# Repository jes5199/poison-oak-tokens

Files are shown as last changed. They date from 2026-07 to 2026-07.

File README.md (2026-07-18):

# Poison-Oak Tokens

Physical tokens to help Scouts learn to recognize poison oak by its
leaves-of-three shape — a safe, touchable way to study the plant, given as a
reward for learning to spot it in the field.

Each token is a printable coin/bead bearing a trifoliate poison-oak leaf,
traced from a real leaf illustration.

<p align="center">
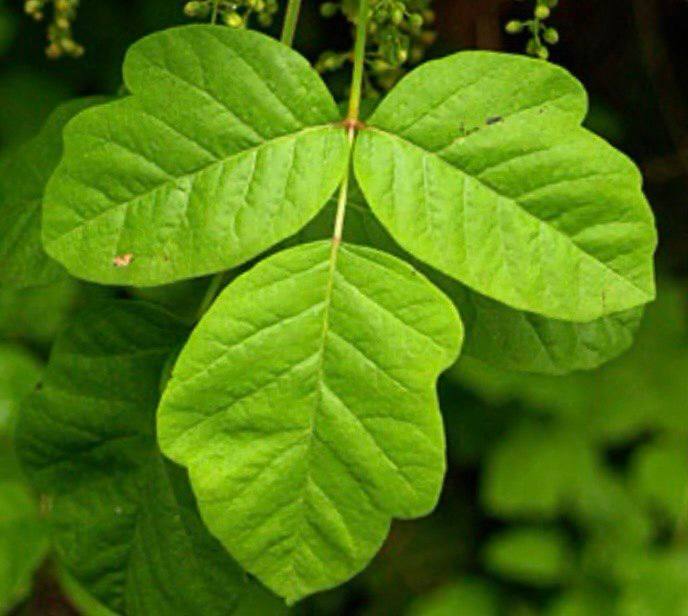
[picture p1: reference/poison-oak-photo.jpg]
Poison oak — real leaf photograph

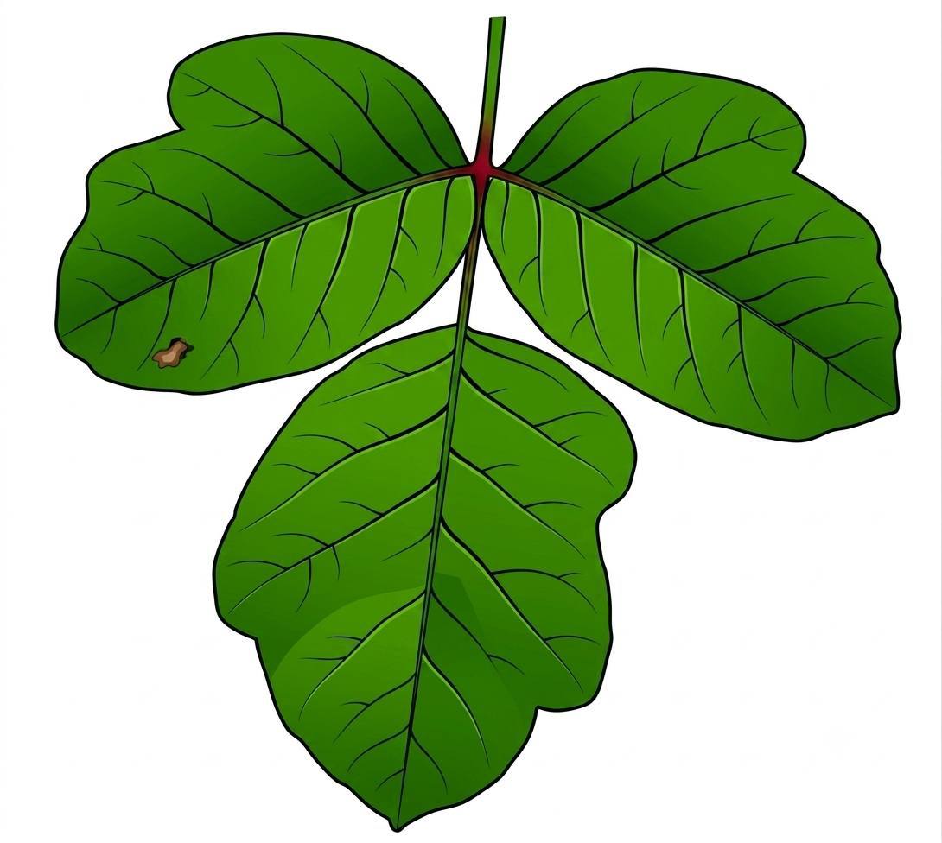
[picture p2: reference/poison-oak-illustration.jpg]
Poison oak illustration — the origin art for the relief

</p>

*Left: the real plant. Right: the illustration the tokens' relief was traced
from (line art extracted by black-hat morphology, baked to grayscale
heightmaps, embossed via OpenSCAD `surface()`).* Three final designs, each
a self-contained OpenSCAD model: the `.scad` plus the two grayscale heightmaps
in its folder reproduce the STL exactly.

| Token | Design | Hole | Thickness |
|---|---|---|---|
| **20 mm** (`20mm/`) | Single-vein: one midrib stroke per leaflet | Ø3.0 mm | 3.20 mm |
| **25 mm** (`25mm/`) | The same single-vein design at 1.25× | Ø3.0 mm | 3.20 mm |
| **40 mm** (`40mm/`) | Full veins, bold strokes, on a chunky 5.70 mm deep-relief body | Ø3.0 mm | 5.70 mm |

Every token is a **bead**: a vertical through-hole sits on the stem's own
implied axis (the leaf leans ~5.8° — the hole follows the stem line, not the
coin's centerline), sized for twine and placed tangent to the raised border so
it never cuts the edge ring. The **front** face is an embossed leaf medallion
(raised silhouette, debossed veins, raised border ring running to the rim).
The **back** face is the same leaf engraved as line art, mirrored *and rotated*
so the hole lands on the stem line on both faces, with a thin flat land at the
rim for a clean first layer.

## The tokens

### 20 mm — single vein per leaflet

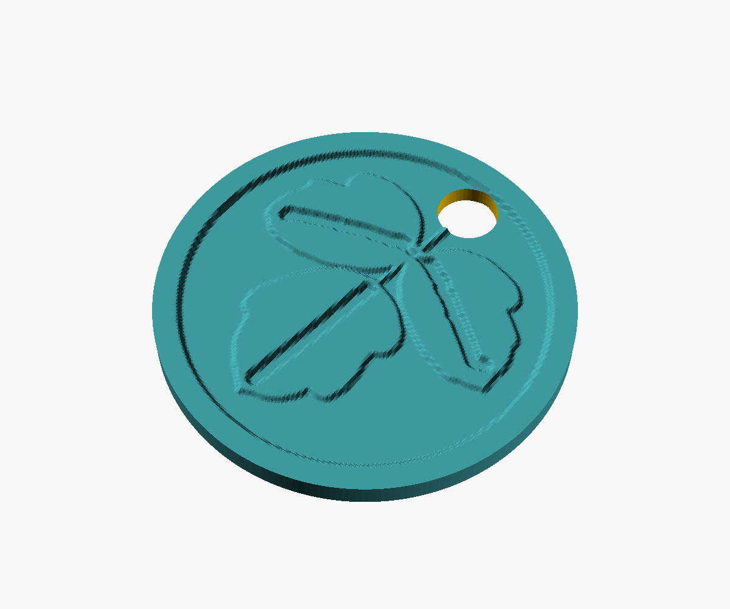
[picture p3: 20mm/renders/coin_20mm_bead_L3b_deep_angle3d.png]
20mm token, angled 3D


| Front (what prints) | Back (what prints) | Top-down 3D | Back face 3D |
|---|---|---|---|
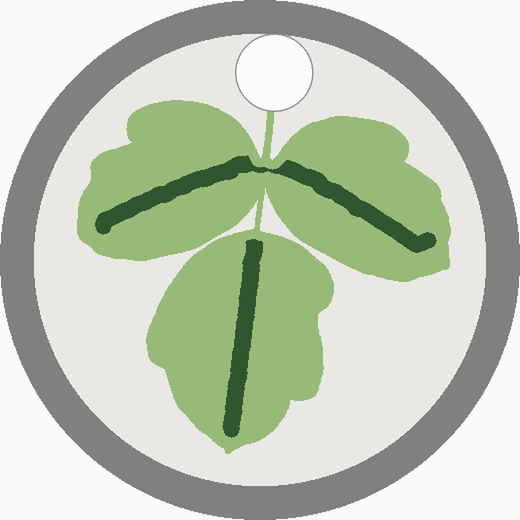
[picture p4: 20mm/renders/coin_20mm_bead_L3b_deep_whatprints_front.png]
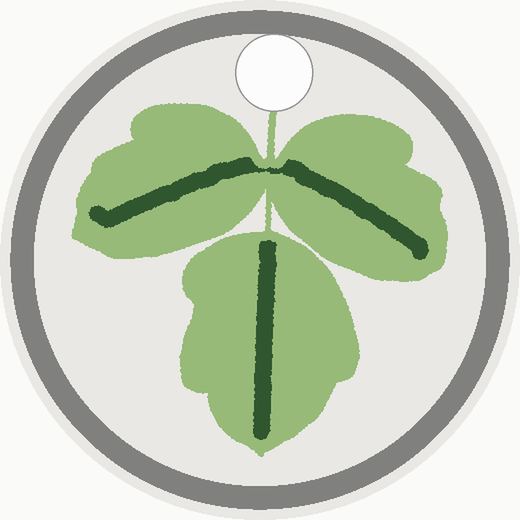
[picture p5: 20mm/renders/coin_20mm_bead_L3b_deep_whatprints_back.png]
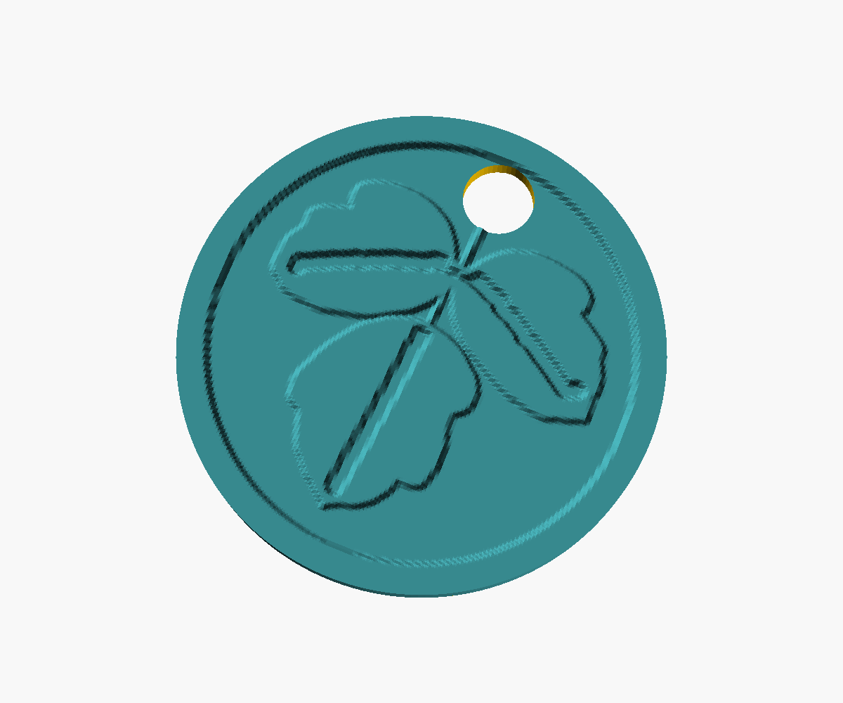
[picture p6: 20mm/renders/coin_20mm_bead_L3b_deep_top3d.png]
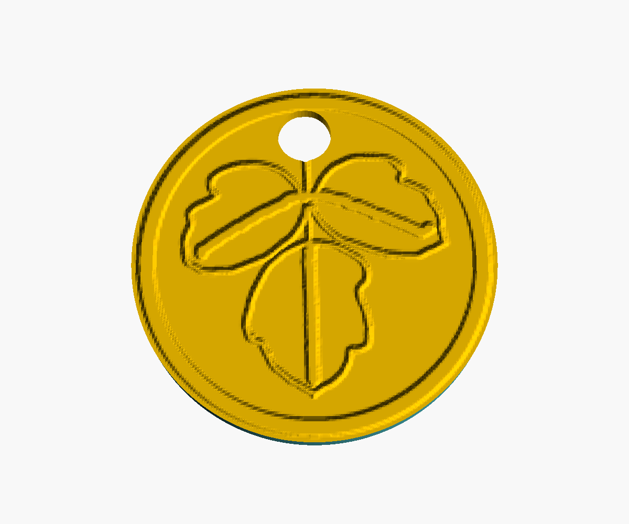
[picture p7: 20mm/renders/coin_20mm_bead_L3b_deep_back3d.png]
|  |  |  |  |

### 25 mm — single vein per leaflet

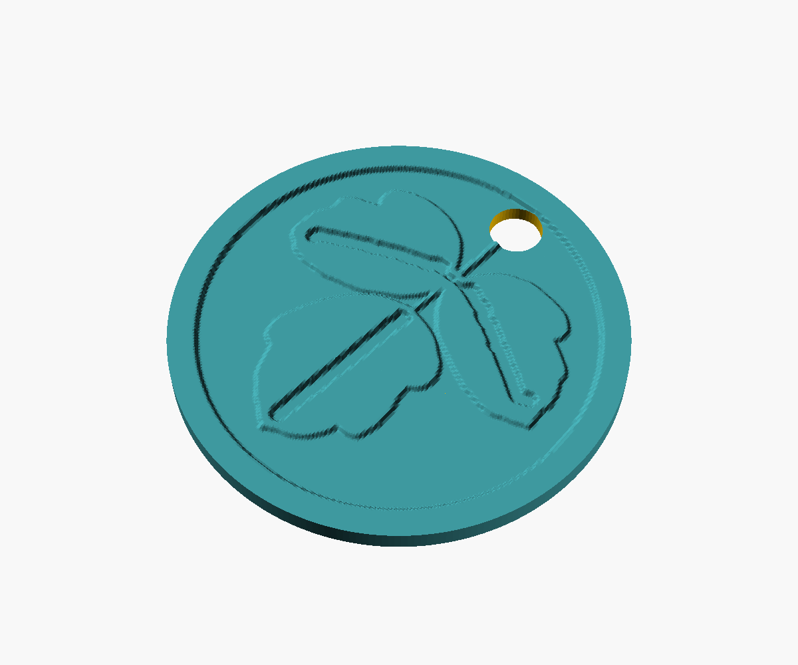
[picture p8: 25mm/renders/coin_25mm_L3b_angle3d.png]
25mm token, angled 3D


| Front (what prints) | Back (what prints) | Top-down 3D | Back face 3D |
|---|---|---|---|
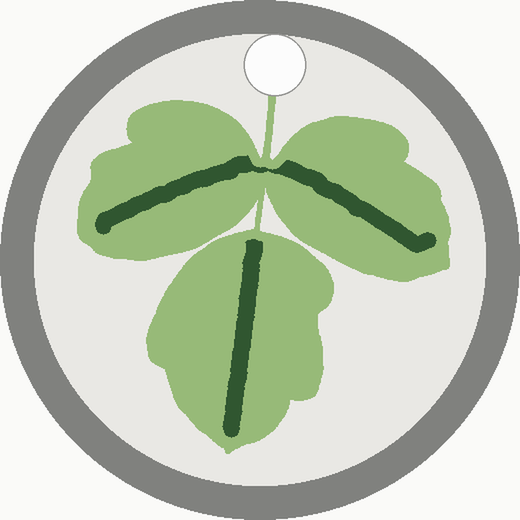
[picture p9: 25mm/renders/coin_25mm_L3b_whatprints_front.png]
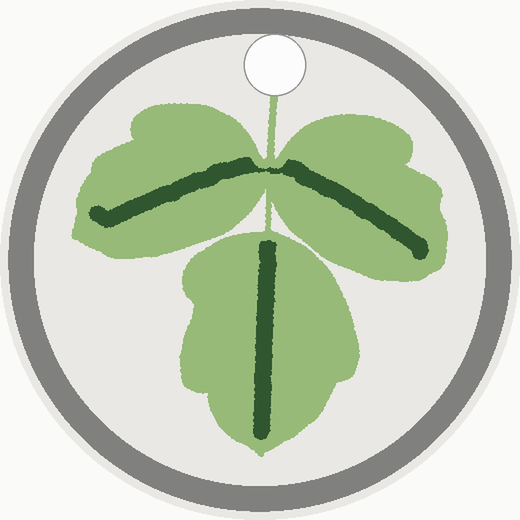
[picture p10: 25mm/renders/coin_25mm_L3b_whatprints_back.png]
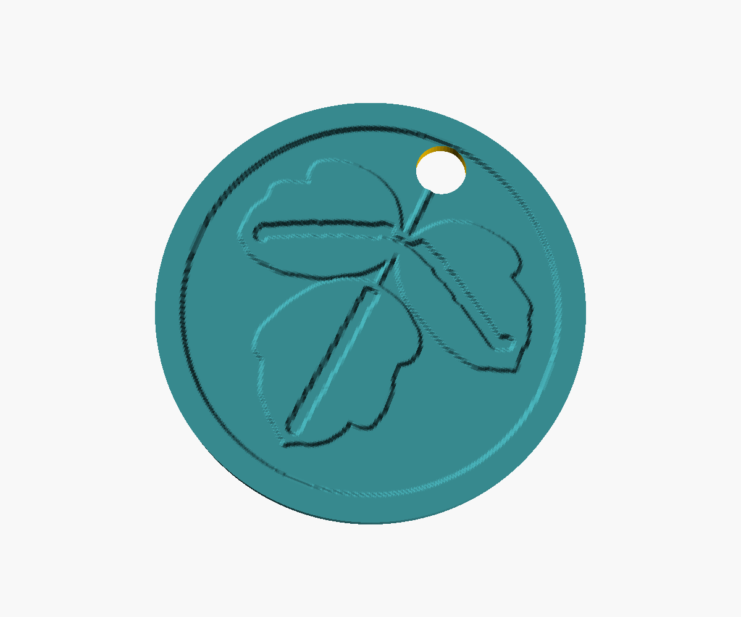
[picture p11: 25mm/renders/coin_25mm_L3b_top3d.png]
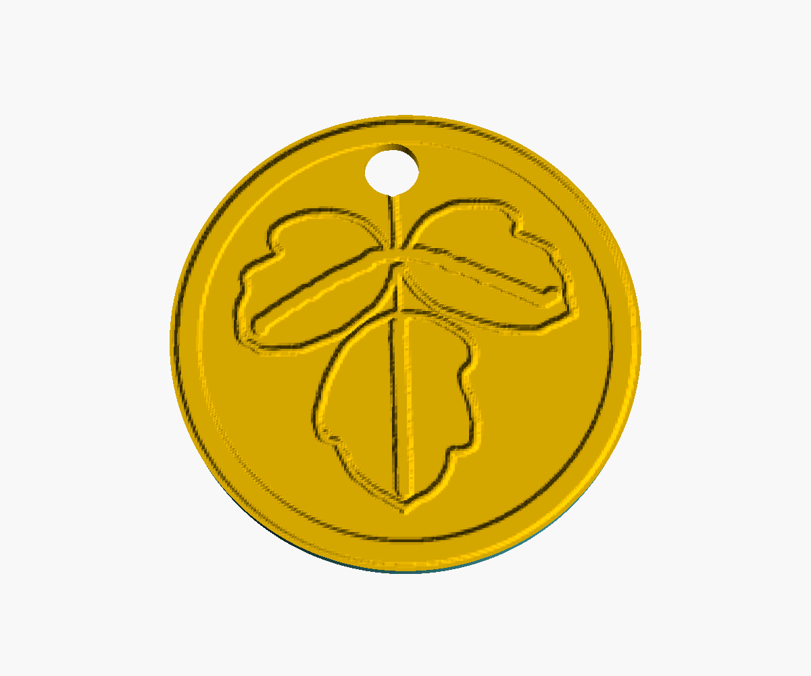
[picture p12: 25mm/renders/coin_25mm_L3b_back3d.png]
|  |  |  |  |

### 40 mm — full veins, deep relief, 5.70 mm body

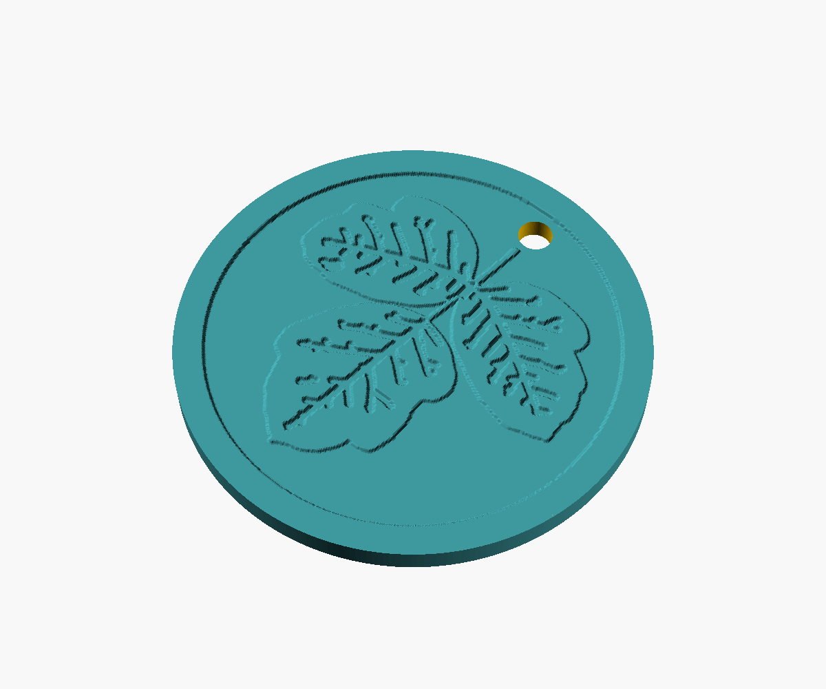
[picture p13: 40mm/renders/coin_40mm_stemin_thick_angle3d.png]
40mm token, angled 3D


| Front (what prints) | Back (what prints) | Top-down 3D | Back face 3D |
|---|---|---|---|
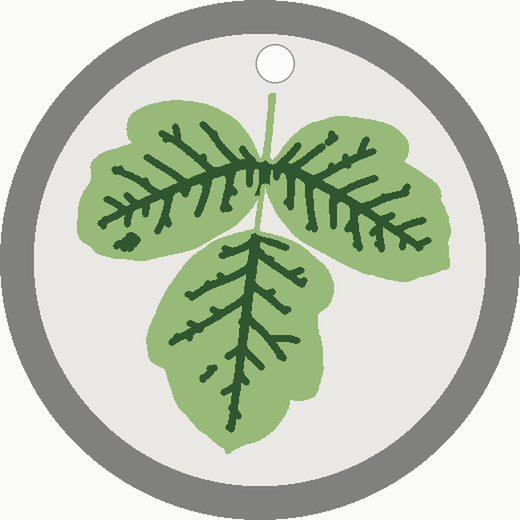
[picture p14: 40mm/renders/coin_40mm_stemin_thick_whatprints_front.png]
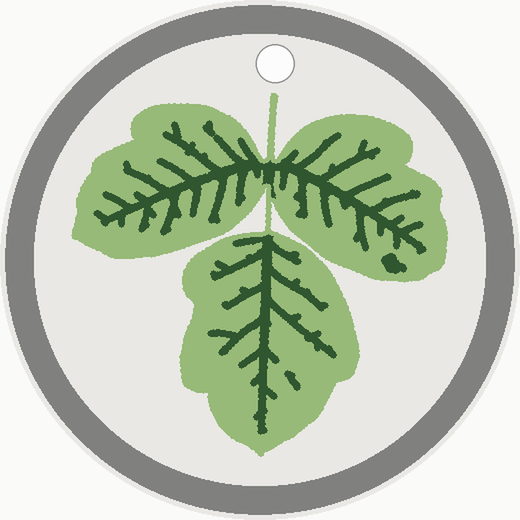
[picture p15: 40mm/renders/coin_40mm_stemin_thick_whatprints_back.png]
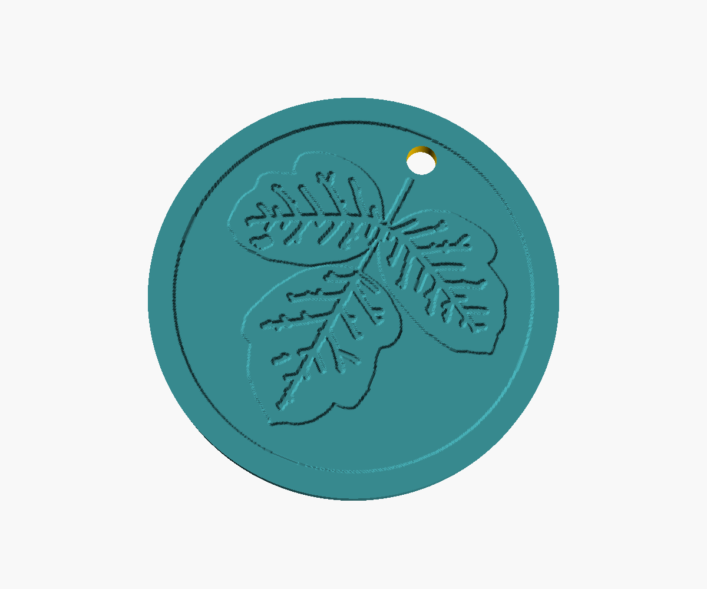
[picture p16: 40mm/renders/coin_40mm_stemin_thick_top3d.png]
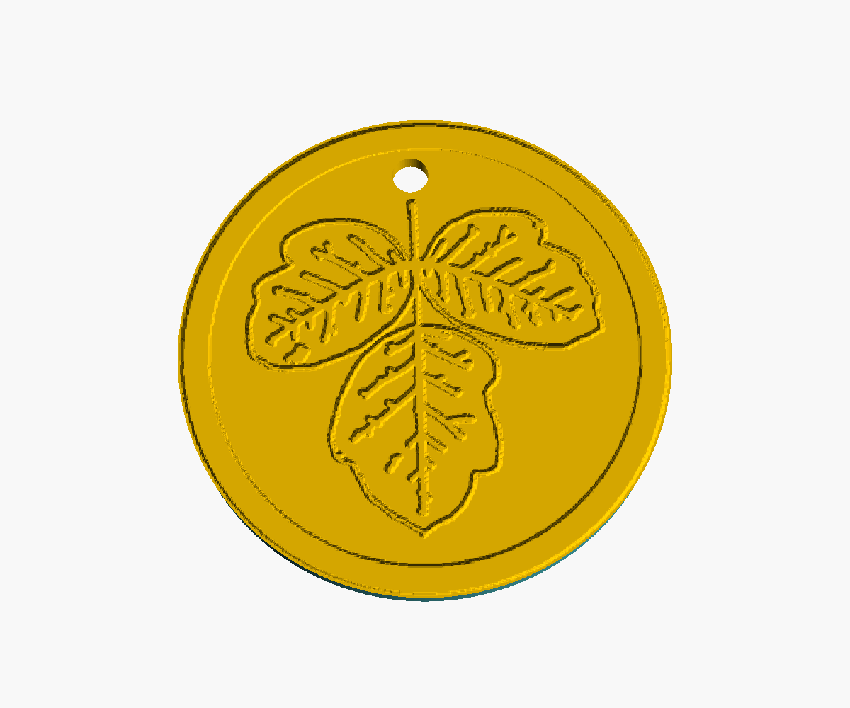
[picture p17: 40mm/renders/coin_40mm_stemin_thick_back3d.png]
|  |  |  |  |

## Folder contents

Each size folder holds:

- `source_leaf.jpg` — the reference photograph the line art was extracted from
  (black-hat morphology → line art → grayscale heightmaps)
- `coin_*.scad` — self-contained OpenSCAD model (reads the heightmaps beside it)
- `heightmap_*.png` / `heightmap_back_*.png` — front relief and back engraving maps
- `coin_*.stl` — the exact accepted mesh (manifold)
- `renders/` — flat "what-prints" views of both faces plus 3D renders
  (top-down, perspective, angled, and the flipped back face)

To rebuild an STL from source:

```
cd 20mm && openscad -o coin_20mm_bead_L3b_deep.stl coin_20mm_bead_L3b_deep.scad
```

## Printing

Printed in **PrusaSlicer using the "0.10 mm SPEED detail" preset** (PLA,
0.4 mm nozzle). Print the **back face down, no supports** — the raised front
medallion has no overhangs, and the back face is flat apart from its engraved
line art.

## Design notes

Feature sizes, for reference:

- Vein/midrib grooves: 0.65 mm wide on the 20 mm, 0.81 mm on the 25 mm,
  0.77 mm on the 40 mm — all sized to span at least two 0.4 mm extrusion
  lines. All grooves are 0.80 mm deep.
- Relief: leaf plateau +0.60 mm, border ring +0.80 mm — exact multiples of
  the 0.1 mm layer height.
- The artwork scales in XY only between sizes; the relief stack stays the
  same. The 40 mm body is doubled to 5.70 mm.
- The bead hole's top edge is tangent to the border ring's inner edge, so the
  border runs unbroken between hole and rim.

## License

Released under **CC0 1.0** (public domain) — see [LICENSE](LICENSE).

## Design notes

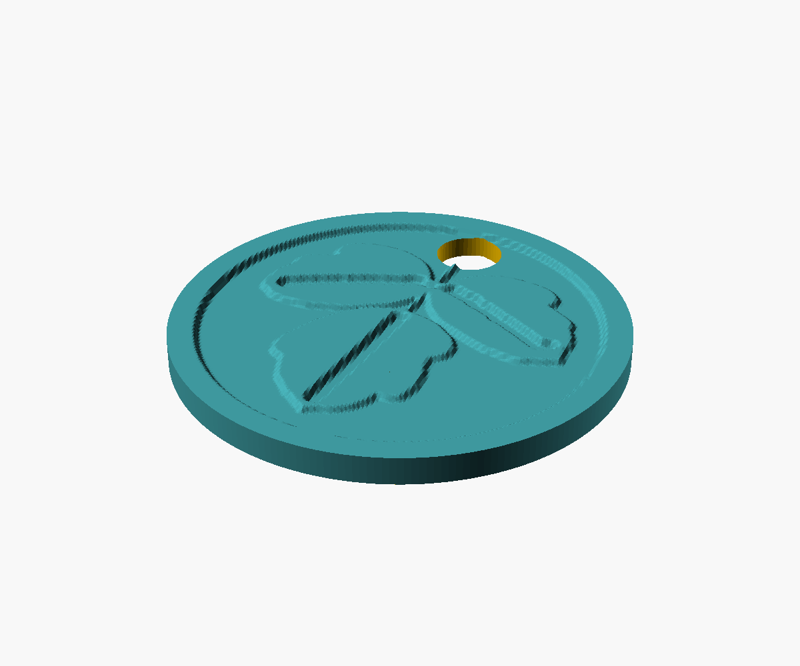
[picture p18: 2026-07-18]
20mm/renders/coin_20mm_bead_L3b_deep_front3d.png

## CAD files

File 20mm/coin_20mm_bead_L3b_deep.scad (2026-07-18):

// 20mm POISON-OAK coin — BEAD v3 "STEM-IN" L3b MINIMAL-VEINS + DEEP variant (jes 2026-07-15)
//
// The v3 stem-in bead (coin_20mm_bead_v3_stemin.scad) with BOLD veins — the
// legibility fix after jes's first print. Recap of the v3 stem-in geometry:
//
//  * Border pushed OUT to the coin edge: front raised ring runs 8.7..10.0mm
//    (the flat lip is gone). Back engraved ring runs 8.7..9.6mm, leaving a
//    0.4mm flat LAND at the rim so the coin still prints clean back-face-down
//    (no undercut lip).
//  * Ø2.50 through-hole on the STEM'S fitted axis (x = 0.1024*y - 0.162, the
//    5.8deg-right lean), TANGENT to the border's inner edge at r=8.7 — the
//    hole touches the border, zero bite. Centre (+0.598, 7.426), so the hole
//    is held by the full-height 1.3mm border ring all the way to the edge.
//  * STEM-IN: the stem is NOT trimmed — it runs into the hole (tip's last
//    ~0.23mm swallowed), the pendant-loop look jes picked. Both faces: the
//    back motif is the mirror ROTATED -9.22deg so the back stem's own axis
//    also passes through the hole (leaflets clear 1.29mm both faces).
//
// L3b MINIMAL VEINS: exactly one stroke per leaflet — each leaflet's midrib
// traced junction->tip through the leaf's own vein tree, free-floating (no
// junction join), ~0.65mm strokes. Back drawing = leaf outline + the same
// three strokes (mirrored + rotated -9.22deg). DEEP relief as the 40mm that
// printed well: leaf plateau +0.60, border +0.80, front grooves 0.80 deep
// (floor 0.20 below the face), back drawing 0.60 deep. Layer-exact at 0.2mm.
// Self-contained: renders coin_20mm_bead_L3b_deep.stl as accepted.
// Heightmaps baked by gen_bead_v3.py from source_leaf.jpg.

diameter = 20;
total_h  = 3.20;                   // DEEP: face 2.40 + border 0.80
hmfile   = "heightmap_20mm_bead_L3b_deep.png";
img      = 160;

back_hm    = "heightmap_back_20mm_bead_L3b_deep.png";
back_depth = 0.60;                 // DEEP back drawing

hole_dia = 3.0;
hole_cx  = 0.572;                  // on the stem axis; top edge tangent to the border
hole_cy  = 7.177;                  // grown Ø2.5->3.0 DOWNWARD (jes): zero border bite kept

flip = false;                      // true = show the underside face up

$fn = 220;

module coin() {
    difference() {
        intersection() {
            scale([diameter/(img-1), diameter/(img-1), total_h/255])
                surface(file = hmfile, center = true, invert = false);
            cylinder(h = total_h * 2 + 2, d = diameter, center = true);
        }
        scale([diameter/(img-1), diameter/(img-1), back_depth/255])
            surface(file = back_hm, center = true, invert = false);
        translate([hole_cx, hole_cy, 0])
            cylinder(h = total_h * 4, d = hole_dia, center = true, $fn = 48);
    }
}

if (flip) rotate([0, 180, 0]) coin();
else coin();

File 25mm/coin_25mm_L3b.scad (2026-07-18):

// 25mm POISON-OAK coin — single-vein (L3b) bead variant (jes 2026-07-15)
//
// The 20mm L3b-Ø3.0 design (coin_20mm_bead_L3b_deep.scad @87c870b) scaled
// 1.25x to Ø25mm, twine hole NOT scaled:
//
//  * Scaled 1.25x: motif, border (raised ring 10.875..12.5mm to the rim,
//    1.63mm wide; back engraved ring 10.875..12.1mm + 0.4mm flat land),
//    the three L3b midrib strokes (0.65 -> 0.81mm, still print-safe).
//  * Kept fixed: hole Ø3.00mm and the deep relief (leaf plateau +0.60,
//    border +0.80, vein grooves 0.80 deep, back drawing 0.60 — heights
//    don't scale for printing; layer-exact at 0.2mm).
//  * Hole on the stem's fitted axis at (+0.754, 9.345): top edge TANGENT to
//    the border's inner edge at r=10.875 — zero bite, both faces. At this
//    size the fixed hole sits near the stem tip (eats 0.16mm — the stem
//    kisses the hole; jes approved as-is). Back motif mirror rotated
//    -9.22deg so the back stem's axis also passes through the hole.
//
// Self-contained: renders coin_25mm_L3b.stl as accepted. 200px heightmaps
// = the same mm/px relief sampling as the 20mm coins' 160px maps.

diameter = 25;
total_h  = 3.20;                   // face 2.40 + border 0.80
hmfile   = "heightmap_25mm_L3b.png";
img      = 200;

back_hm    = "heightmap_back_25mm_L3b.png";
back_depth = 0.60;

hole_dia = 3.0;
hole_cx  = 0.754;                  // on the stem axis; top edge tangent to the border
hole_cy  = 9.345;

flip = false;                      // true = show the underside face up

$fn = 240;

module coin() {
    difference() {
        intersection() {
            scale([diameter/(img-1), diameter/(img-1), total_h/255])
                surface(file = hmfile, center = true, invert = false);
            cylinder(h = total_h * 2 + 2, d = diameter, center = true);
        }
        scale([diameter/(img-1), diameter/(img-1), back_depth/255])
            surface(file = back_hm, center = true, invert = false);
        translate([hole_cx, hole_cy, 0])
            cylinder(h = total_h * 4, d = hole_dia, center = true, $fn = 48);
    }
}

if (flip) rotate([0, 180, 0]) coin();
else coin();

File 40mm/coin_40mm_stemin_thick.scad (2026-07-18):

// 40mm POISON-OAK coin — THICK+DEEP bead variant (jes 2026-07-15, STL-only)
//
// The v3 stem-in design scaled 2x to Ø40mm, with the twine hole NOT scaled:
//
//  * Motif + border scaled 2x: raised border ring 17.4..20.0mm on the front
//    (runs to the coin rim, no flat lip, now 2.6mm wide); back engraved ring
//    17.4..19.6mm leaving the 0.4mm flat LAND at the rim (clean back-face-down
//    print). Relief depths KEPT (2.85mm coin, +0.40 leaf, -0.30 veins, +0.45
//    border, 0.40 back grooves — heights don't scale for printing).
//  * THICK: whole coin doubled to 5.70mm total (face field 4.90mm).
//  * DEEP relief on the bold-width art (0.77mm strokes): leaf plateau +0.60,
//    border +0.80, front grooves 0.80 deep (floor 0.20 below the face),
//    back drawing 0.80 deep. All exact 0.2mm-layer multiples.
//  * Hole KEPT at a fixed twine size, Ø3.00mm, centred on the STEM'S fitted
//    axis at the MIDPOINT of stem-tip -> border-inner-edge: (+1.218, 15.074).
//    Fully clean: 0.77mm gap to the stem tip, 0.78mm to the border wall,
//    leaflets 3.78mm. Web to the rim: 0.78mm face + 2.6mm full-height border.
//  * Back motif = mirror ROTATED -9.24deg so the back stem's own axis also
//    passes through the hole (hole on the stem line on BOTH faces).
//
// Self-contained: renders coin_40mm_stemin_thick.stl as accepted.
// Heightmaps (320px, matching the 20mm coins' relief sampling) baked by
// gen_coin40.py from source_leaf.jpg.

diameter = 40;
total_h  = 5.70;                   // THICK: 2x base (face 4.90) + 0.80 border
hmfile   = "heightmap_40mm_stemin_thick.png";
img      = 320;

back_hm    = "heightmap_back_40mm_stemin_thick.png";
back_depth = 0.80;                 // DEEP back drawing

hole_dia = 3.0;
hole_cx  = 1.218;                  // midpoint of stem-tip -> border wall, on the axis
hole_cy  = 15.074;

flip = false;                      // true = show the underside face up

$fn = 280;

module coin() {
    difference() {
        intersection() {
            scale([diameter/(img-1), diameter/(img-1), total_h/255])
                surface(file = hmfile, center = true, invert = false);
            cylinder(h = total_h * 2 + 2, d = diameter, center = true);
        }
        scale([diameter/(img-1), diameter/(img-1), back_depth/255])
            surface(file = back_hm, center = true, invert = false);
        translate([hole_cx, hole_cy, 0])
            cylinder(h = total_h * 4, d = hole_dia, center = true, $fn = 64);
    }
}

if (flip) rotate([0, 180, 0]) coin();
else coin();

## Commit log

2026-07-18 Poison-oak tokens: three final designs (20mm no-veins, 25mm single-vein, 40mm full-vein)
    Structure + sources (reference photo, self-contained .scad, heightmaps) +
    final STLs for all three, plus the render sets already in hand (full 40mm,
    25mm what-prints). Remaining renders follow in per-token commits.
    [coin_20mm_bead_noveins.scad, coin_25mm_L3b.scad, coin_40mm_stemin.scad]
2026-07-18 Add 40mm-thick token (maker's preferred 40mm): sources + STL
    [coin_40mm_stemin_thick.scad]
2026-07-18 Add 20mm render set (whatprints both faces + top/front/angle/back 3D)
2026-07-18 Keep only the thicker 40mm per maker
    The standard 2.85mm bold-veins 40mm is removed; the 5.70mm deep-relief
    version (the maker's preferred print) is now the canonical /40mm token.
    [coin_40mm_stemin.scad, coin_40mm_stemin_thick.scad]
2026-07-18 Fix layer height to 0.1mm + reconcile depth notes
2026-07-18 Add 25mm render set (top/front/angle/back 3D)
2026-07-18 Swap 20mm to the single-vein design per maker
    The no-veins 20mm is replaced by the single-midrib-per-leaflet version
    (the design the 25mm is scaled from): 0.65mm strokes, 0.80mm-deep
    grooves, same Ø3.0 border-tangent hole. 3D renders follow.
    [coin_20mm_bead_L3b_deep.scad, coin_20mm_bead_noveins.scad]
2026-07-18 Use real print recipe: PrusaSlicer 0.10mm SPEED preset
2026-07-18 Add 20mm single-vein render set + complete its README showcase
2026-07-18 Trim print notes to the real recipe only
2026-07-18 Correct preset name: 0.10mm SPEED detail
2026-07-18 Add 40mm render set + complete its README showcase
